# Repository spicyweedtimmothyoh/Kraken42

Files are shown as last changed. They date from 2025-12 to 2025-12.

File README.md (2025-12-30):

<div align="center">

# 🦑 Kraken42

### *Kraken themed ergonomic split keyboard heavily inspired by the Corne layout*







---
<p align="center">
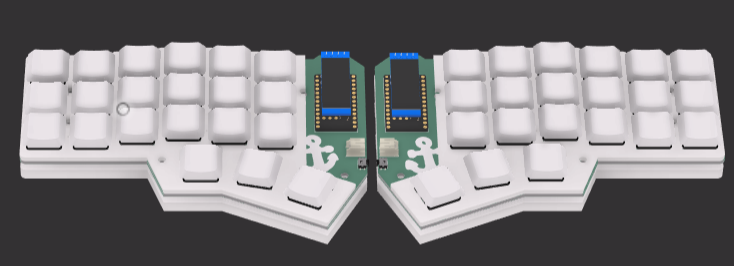
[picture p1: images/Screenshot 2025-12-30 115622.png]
  
</p>

</div>

## Features

- Staggered

- 40% layout

- 3 thumb keys

- Choc V1 switches

- Wireless

## PCB
Designed with KiCad
- 2 layers
- Silkscreen graphics
- Controlled by 2x Supermini NRF52840

 #### Schematic
  <p align="center">
  
</p>

  #### PCB Layout

<p align="center">
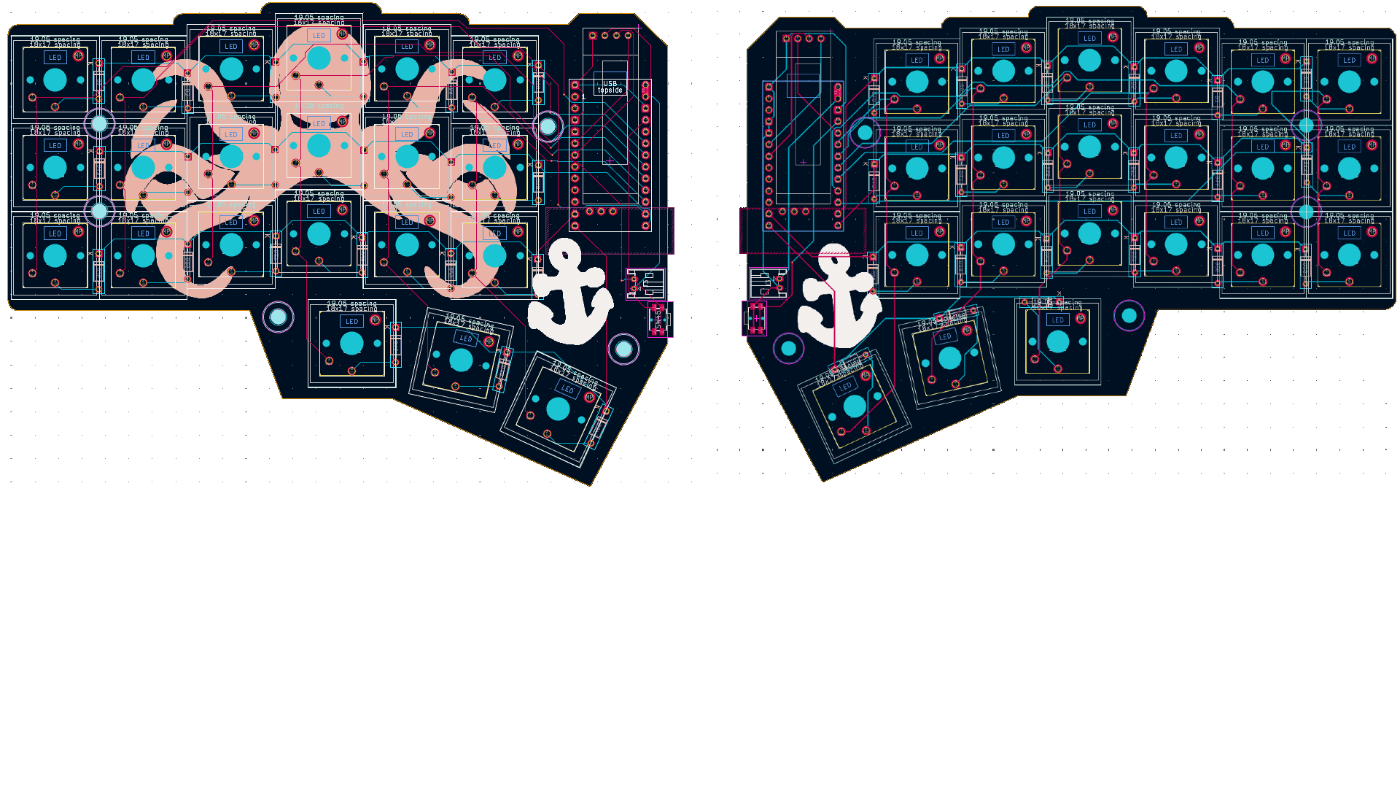
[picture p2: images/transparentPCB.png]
  
</p>

## CAD
Designed with Fusion 360
- Low-profile
- includes plates and bottom cases
- assembled using 5x2 M3 screws

  <p align="center">
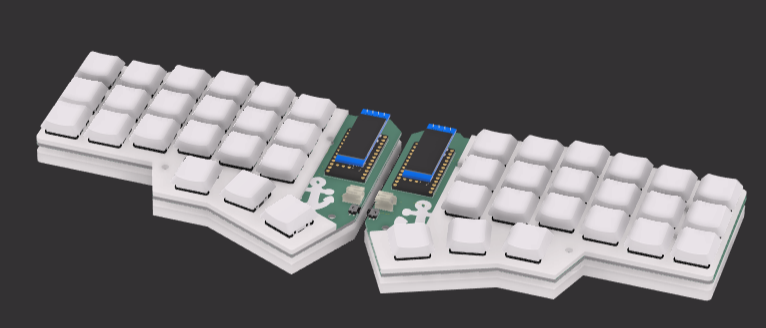
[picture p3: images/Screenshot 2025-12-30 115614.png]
  
</p>

<p align="center">
  
</p>

## BOM

| Product | Quantity | Source | Price($) | Link |
| :-----: | :-----: | :-----: | :-----: | :-----: |
| Kailh Choc Low Profile Switches 10x | 5 | Typeractive | 35 | [here](https://typeractive.xyz/products/choc-switches?variant=45741919273191) |
| Battery Jack | 2 | Typeractive | 2 | [here](https://typeractive.xyz/products/battery-jack?variant=46024892186855) |
| Reset Button | 2 | Typeractive | 3 | [here](https://typeractive.xyz/products/reset-button?variant=45597784932583) |
| MBK Choc Keycaps 1u 10x | 5 | Typeractive | 20 | [here](https://typeractive.xyz/products/mbk-keycaps?variant=48512019562727) |
| Lithium Battery 110mah | 2 | Typeractive | 8 | [here](https://typeractive.xyz/products/lithium-battery-110mah?variant=46118748291303) |
| Diodes 50x | 1 | aliexpress | 1 | [here](https://www.aliexpress.us/item/3256809437175218.html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) |
| 0.91" OLED 5x | 1 | aliexpress | 1 | [here](https://www.aliexpress.us/item/3256804386173217.html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) |
| NRF52840 | 2 | aliexpress | 6.6 | [here](https://www.aliexpress.us/item/3256804386173217.html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) |
| Left & Right PCB + Shipping | 5 | JLCPCB | 27.06 | - |

### Subtotal : 103.66

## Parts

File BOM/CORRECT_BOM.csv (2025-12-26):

Product | Quantity | Source | Price($) | Link
Kailh Choc Low Profile Switches 10x | 5 | Typeractive | 35 | here
Battery Jack | 2 | Typeractive | 2 | here
Reset Button | 2 | Typeractive | 3 | here
MBK Choc Keycaps 1u 10x | 5 | Typeractive | 20 | here
Lithium Battery 110mah | 2 | Typeractive | 8 | here
Diodes 50x | 1 | aliexpress | 1 | here
0.91" OLED 5x | 1 | aliexpress | 1 | here
NRF52840 | 2 | aliexpress | 6.6 | here
Left & Right PCB + Shipping | 5 | JLCPCB | 27.06 | -

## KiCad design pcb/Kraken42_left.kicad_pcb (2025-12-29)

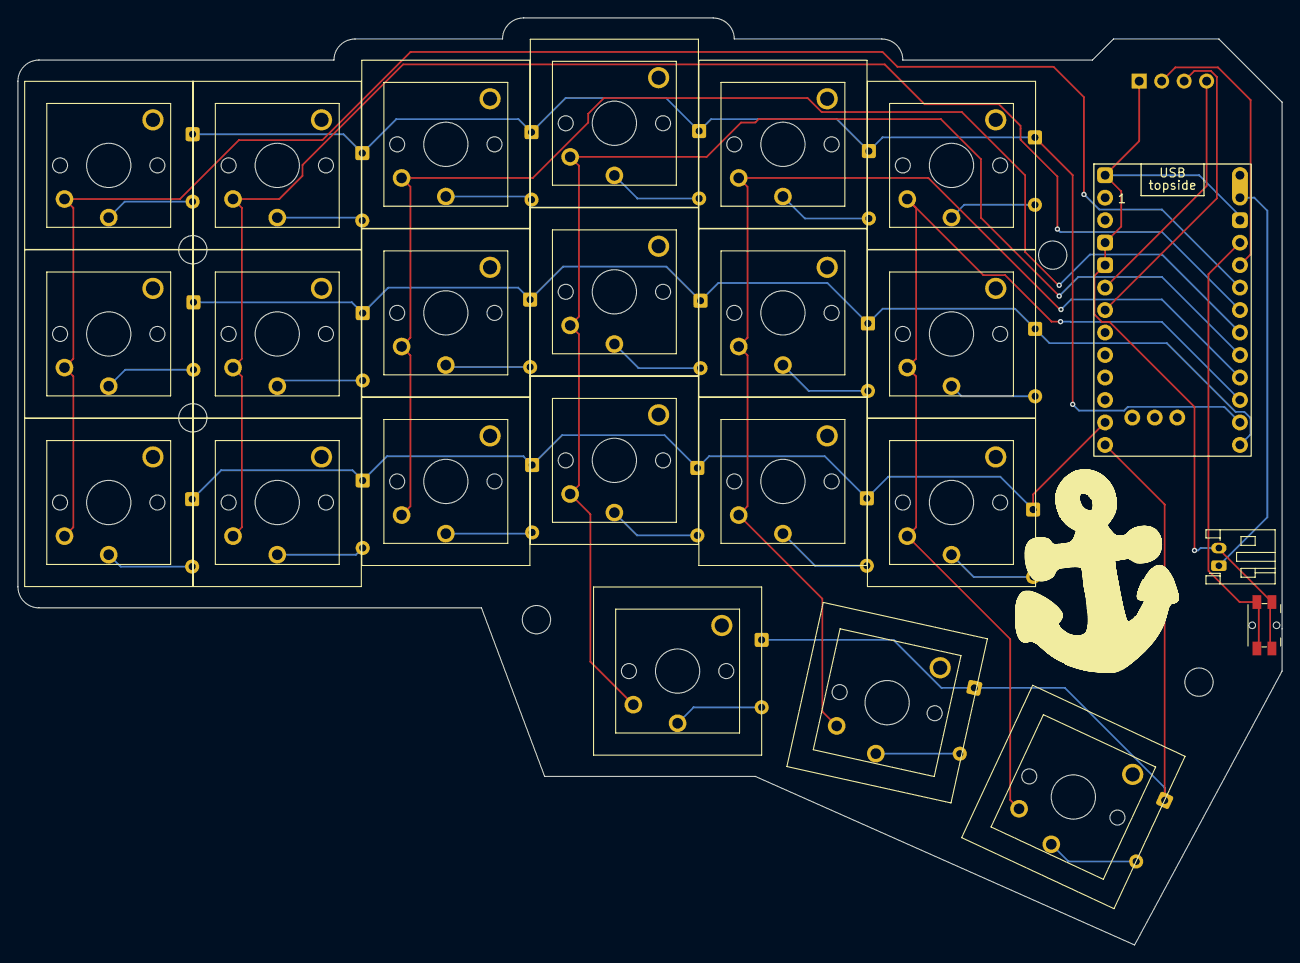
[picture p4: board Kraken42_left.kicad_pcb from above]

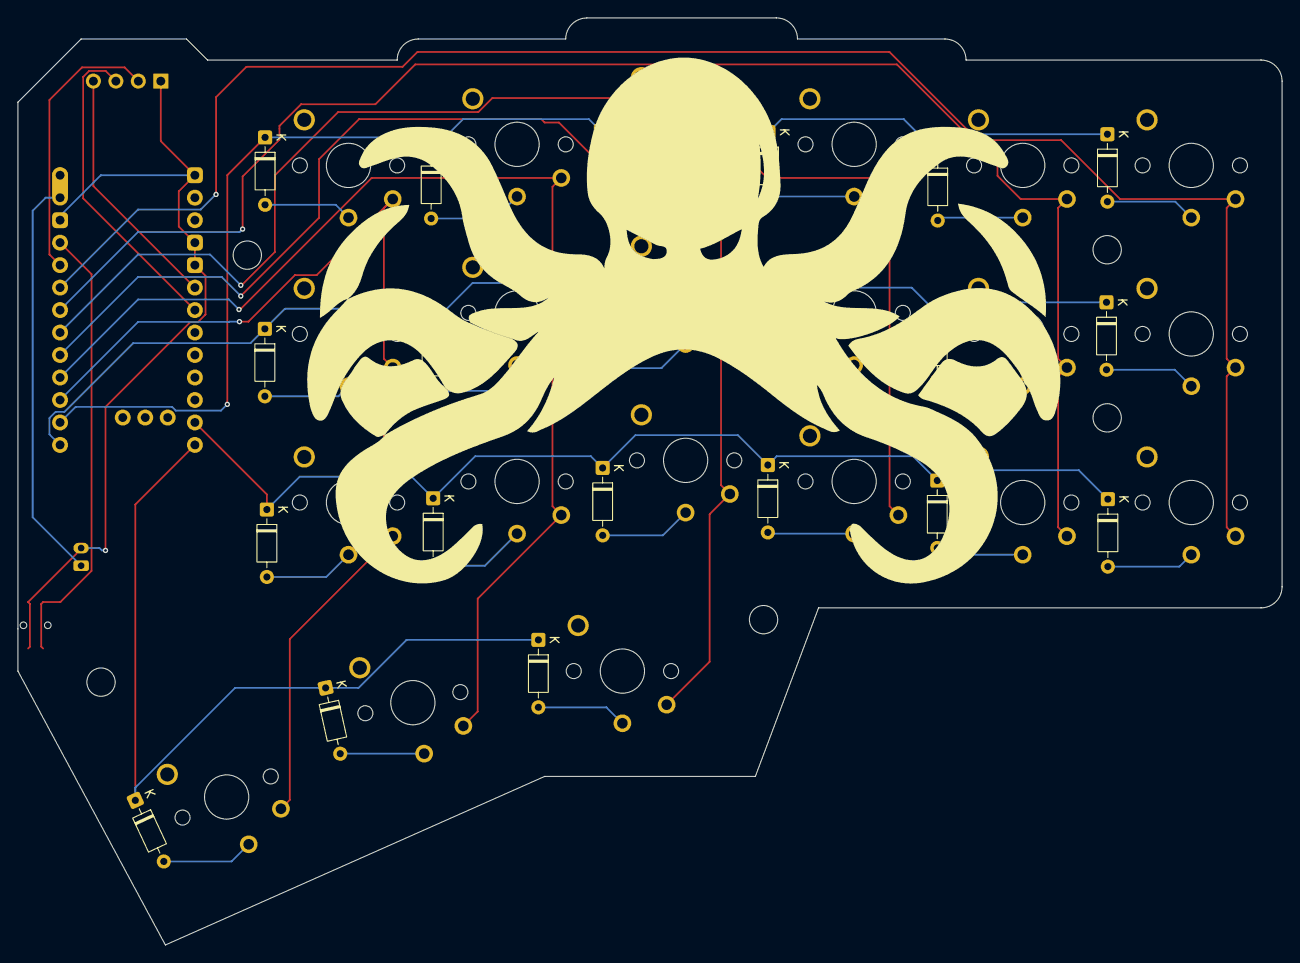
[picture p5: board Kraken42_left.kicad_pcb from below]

Board: 2 copper layers, 142.9 x 104.8 mm, 51 parts (21 on the bottom side), 37 nets.

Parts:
D1, D3, D5, D6, D9, D10, D13, D14, D15, D16, D17, D18, D25, D26, D27, D28, D29, D30, D37, D39, D41: D; D_DO-35_SOD27_P7.62mm_Horizontal
H1, H3, H4, H5, H6: MountingHole; MountingHole_3.2mm_M3
J1: OLED-128x32; OLED-128x32-cutout
J3: Conn_01x02_Socket; JST_PH_S2B-PH-K_1x02_P2.00mm_Horizontal
SW1, SW3, SW5, SW6, SW9, SW10, SW13, SW14, SW15, SW16, SW17, SW18, SW25, SW26, SW27, SW28, SW29, SW30, SW37, SW39, SW41: SW_Push; SW_choc_v1+v2_1u
SW45: SW_Push; Panasonic_EVQPUL_EVQPUC
U1: SuperMini nRF52840; SuperMini_nRF52840_AH_USBup

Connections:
COL0: SW1.1, SW13.1, SW25.1, U1.17 (P0.31-LF)
COL1: SW3.1, SW14.1, SW26.1, U1.18 (P0.29-LF)
COL2: SW5.1, SW15.1, SW27.1, U1.19 (P0.02-LF)
COL3: SW6.1, SW16.1, SW28.1, SW41.1, U1.20 (P1.15-LF)
COL4: SW9.1, SW17.1, SW29.1, SW39.1, U1.21 (P1.13-LF)
COL5: SW10.1, SW18.1, SW30.1, SW37.1, U1.22 (P1.11-LF)
GND: J1.1 (GND), J3.2, SW45.1, U1.3 (GND), U1.4 (GND), U1.14 (GND), U1.28 (GND)
unnamed: D1.2 (A), SW1.2
unnamed: D3.2 (A), SW3.2
unnamed: D5.2 (A), SW5.2
unnamed: D6.2 (A), SW6.2
unnamed: D9.2 (A), SW9.2
unnamed: D10.2 (A), SW10.2
unnamed: D13.2 (A), SW13.2
unnamed: D14.2 (A), SW14.2
unnamed: D15.2 (A), SW15.2
unnamed: D16.2 (A), SW16.2
unnamed: D17.2 (A), SW17.2
unnamed: D18.2 (A), SW18.2
unnamed: D25.2 (A), SW25.2
unnamed: D26.2 (A), SW26.2
unnamed: D27.2 (A), SW27.2
unnamed: D28.2 (A), SW28.2
unnamed: D29.2 (A), SW29.2
unnamed: D30.2 (A), SW30.2
unnamed: D37.2 (A), SW37.2
unnamed: D39.2 (A), SW39.2
unnamed: D41.2 (A), SW41.2
unnamed: J3.1, U1.13 (BAT+), U1.29 (BAT+)
RESET: SW45.2, U1.15 (RST)
ROW0: D1.1 (K), D3.1 (K), D5.1 (K), D6.1 (K), D9.1 (K), D10.1 (K), U1.23 (P0.10-LF)
ROW1: D13.1 (K), D14.1 (K), D15.1 (K), D16.1 (K), D17.1 (K), D18.1 (K), U1.24 (P0.09-LF)
ROW2: D25.1 (K), D26.1 (K), D27.1 (K), D28.1 (K), D29.1 (K), D30.1 (K), U1.11 (P1.04-LF)
ROW3: D37.1 (K), D39.1 (K), D41.1 (K), U1.12 (P1.06-LF)
SCK: J1.3 (SCL), U1.6 (P0.20)
SDA: J1.4 (SDA), U1.5 (P0.17)
VCC: J1.2 (VCC), U1.16 (3V3)
